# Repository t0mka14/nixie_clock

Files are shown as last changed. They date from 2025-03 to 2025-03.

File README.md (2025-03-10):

Another 6 digit nixie clock project. Uses Z570M digitrons, RpiPico and HV5530

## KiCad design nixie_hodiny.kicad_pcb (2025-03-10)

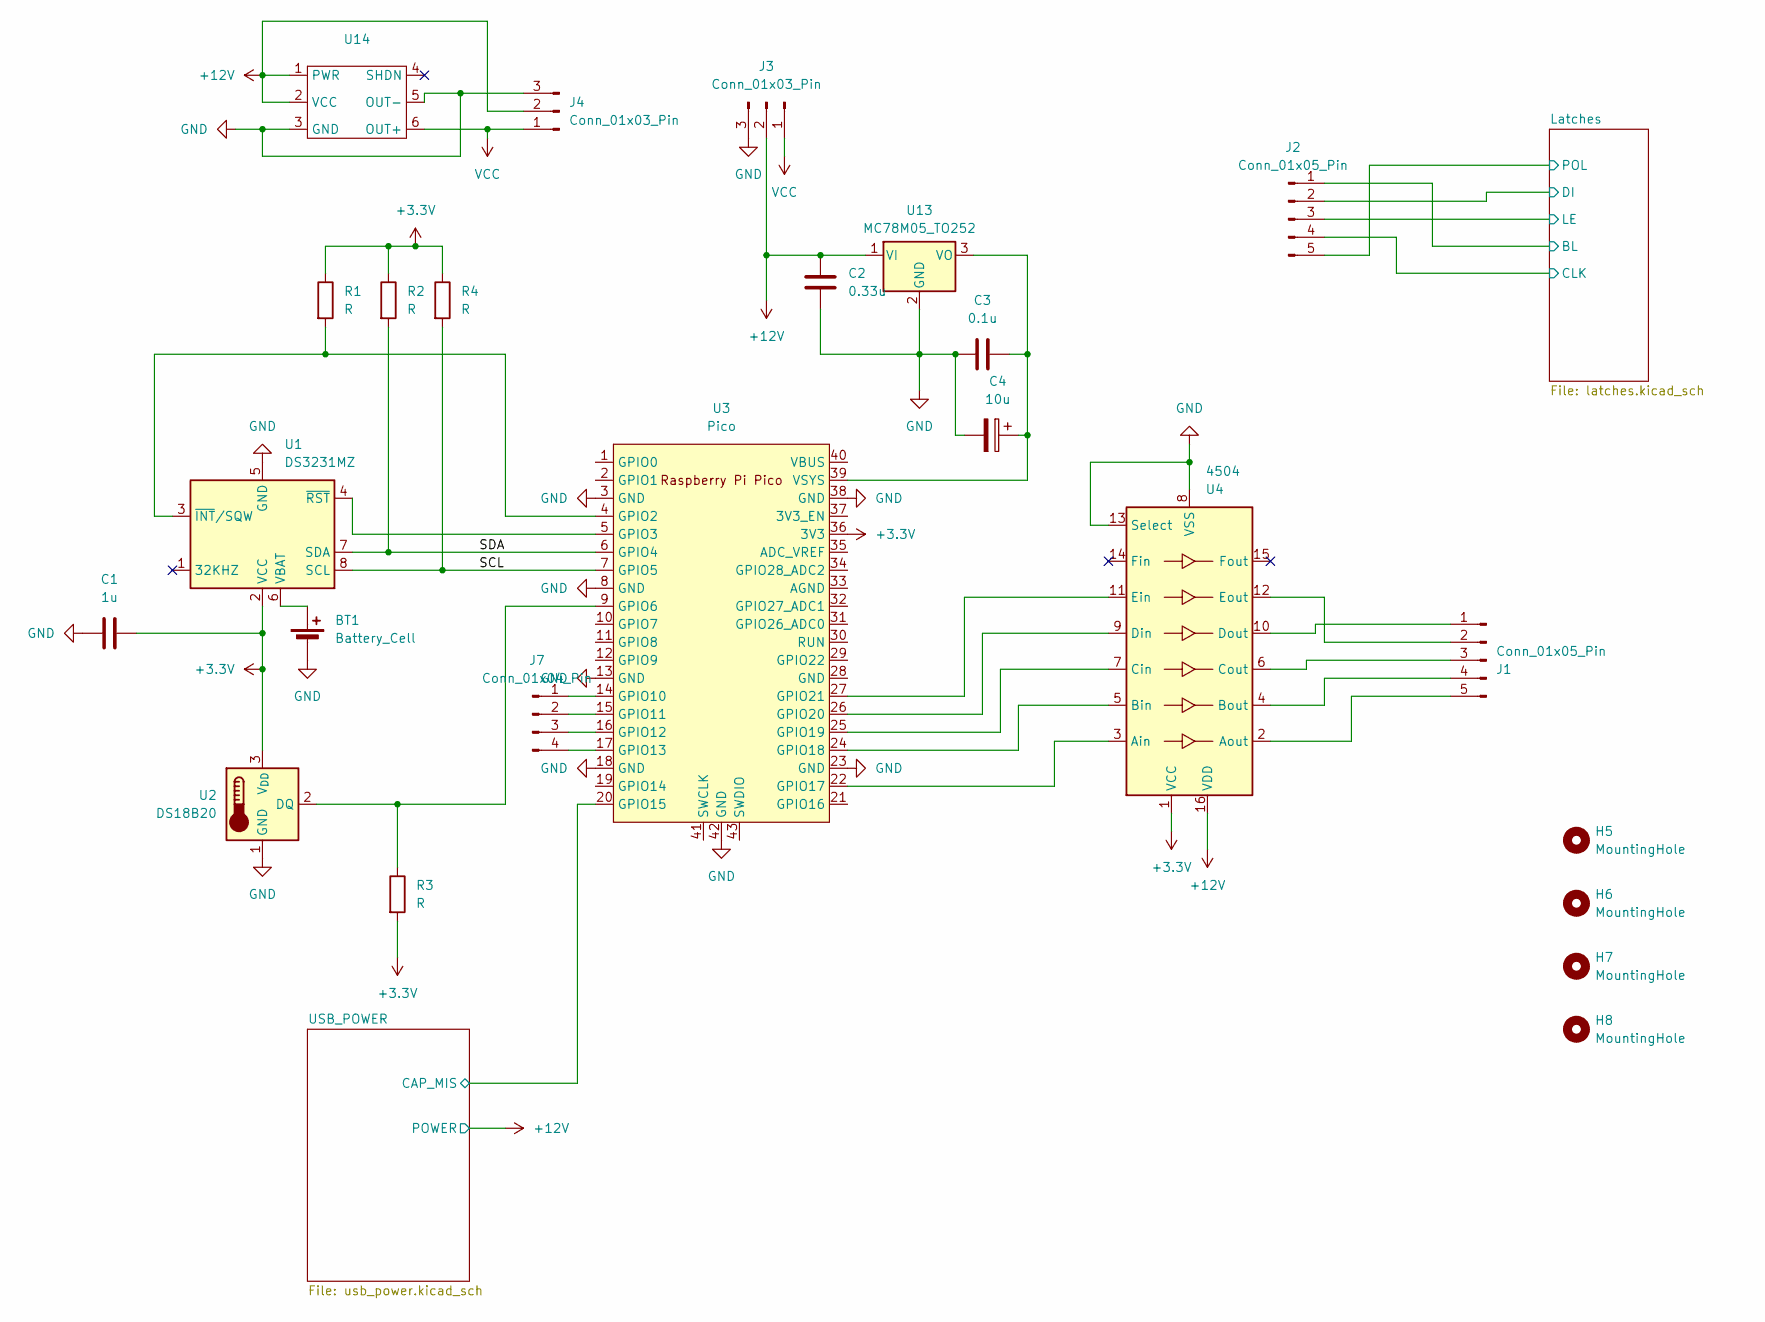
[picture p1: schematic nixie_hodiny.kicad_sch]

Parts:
BT1: Battery_Cell; Battery_Panasonic_CR2032-HFN_Horizontal_CircularHoles
C1: 1u; C_0805_2012Metric
C2: 0.33u; C_0805_2012Metric
C3: 0.1u; C_0805_2012Metric
C4: 10u; CP_Radial_D5.0mm_P2.00mm
H5, H6, H7, H8: MountingHole; MountingHole_3.2mm_M3
J1, J2: Conn_01x05_Pin; PinHeader_1x05_P2.54mm_Vertical
J3, J4: Conn_01x03_Pin; PinHeader_1x03_P2.54mm_Vertical
J7: Conn_01x04_Pin; PinHeader_1x04_P2.54mm_Vertical
R1, R2, R3, R4: R; R_0805_2012Metric
U1: DS3231MZ; SOIC-8_3.9x4.9mm_P1.27mm
U2: DS18B20; TO-92_Inline
U3: Pico; RPi_Pico_SMD_TH
U4: 4504; Texas_PDSO_G16
U13: MC78M05_TO252; TO-252-2
U14: nixie_supply

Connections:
+3.3V: C1.2, R1.1, R2.1, R3.2, R4.1, U1.2 (VCC), U2.3 (V_{DD}), U3.36 (3V3), U4.1 (VCC)
+12V: C2.1, J3.2, J4.2, U4.16 (VDD), U13.1 (VI), U14.1 (PWR), U14.2 (VCC); also elsewhere on the board
/Latches/BL: J2.1; also elsewhere on the board
/Latches/CLK: J2.4; also elsewhere on the board
/Latches/DI: J2.2; also elsewhere on the board
/Latches/LE: J2.3; also elsewhere on the board
/Latches/POL: J2.5; also elsewhere on the board
/SCL: R4.2, U1.8 (SCL), U3.7 (GPIO5)
/SDA: R2.2, U1.7 (SDA), U3.6 (GPIO4)
/USB_POWER/CAP_MIS: U3.20 (GPIO15); also elsewhere on the board
GND: BT1.2 (-), C1.1, C2.2, C3.1, C4.2, J3.3, J4.3, U1.5 (GND), U2.1 (GND), U3.3 (GND), U3.8 (GND), U3.13 (GND), U3.18 (GND), U3.23 (GND), U3.38 (GND), U3.42 (GND), U4.8 (VSS), U4.13 (Select), U13.2 (GND), U14.3 (GND), U14.5 (OUT-); also elsewhere on the board
unnamed: BT1.1 (+), U1.6 (VBAT)
unnamed: J1.1, U4.10 (Dout)
unnamed: J1.2, U4.12 (Eout)
unnamed: J1.3, U4.6 (Cout)
unnamed: J1.4, U4.4 (Bout)
unnamed: J1.5, U4.2 (Aout)
unnamed: J7.1, U3.14 (GPIO10)
unnamed: J7.2, U3.15 (GPIO11)
unnamed: J7.3, U3.16 (GPIO12)
unnamed: J7.4, U3.17 (GPIO13)
unnamed: R1.2, U1.3 (~INT/SQW), U3.4 (GPIO2)
unnamed: U1.4 (~RST), U3.5 (GPIO3)
unnamed: R3.1, U2.2 (DQ), U3.9 (GPIO6)
unnamed: U3.22 (GPIO17), U4.3 (Ain)
unnamed: U3.24 (GPIO18), U4.5 (Bin)
unnamed: U3.25 (GPIO19), U4.7 (Cin)
unnamed: U3.26 (GPIO20), U4.9 (Din)
unnamed: U3.27 (GPIO21), U4.11 (Ein)
unnamed: C3.2, C4.1, U3.39 (VSYS), U13.3 (VO)
VCC: J3.1, J4.1, U14.6 (OUT+); also elsewhere on the board

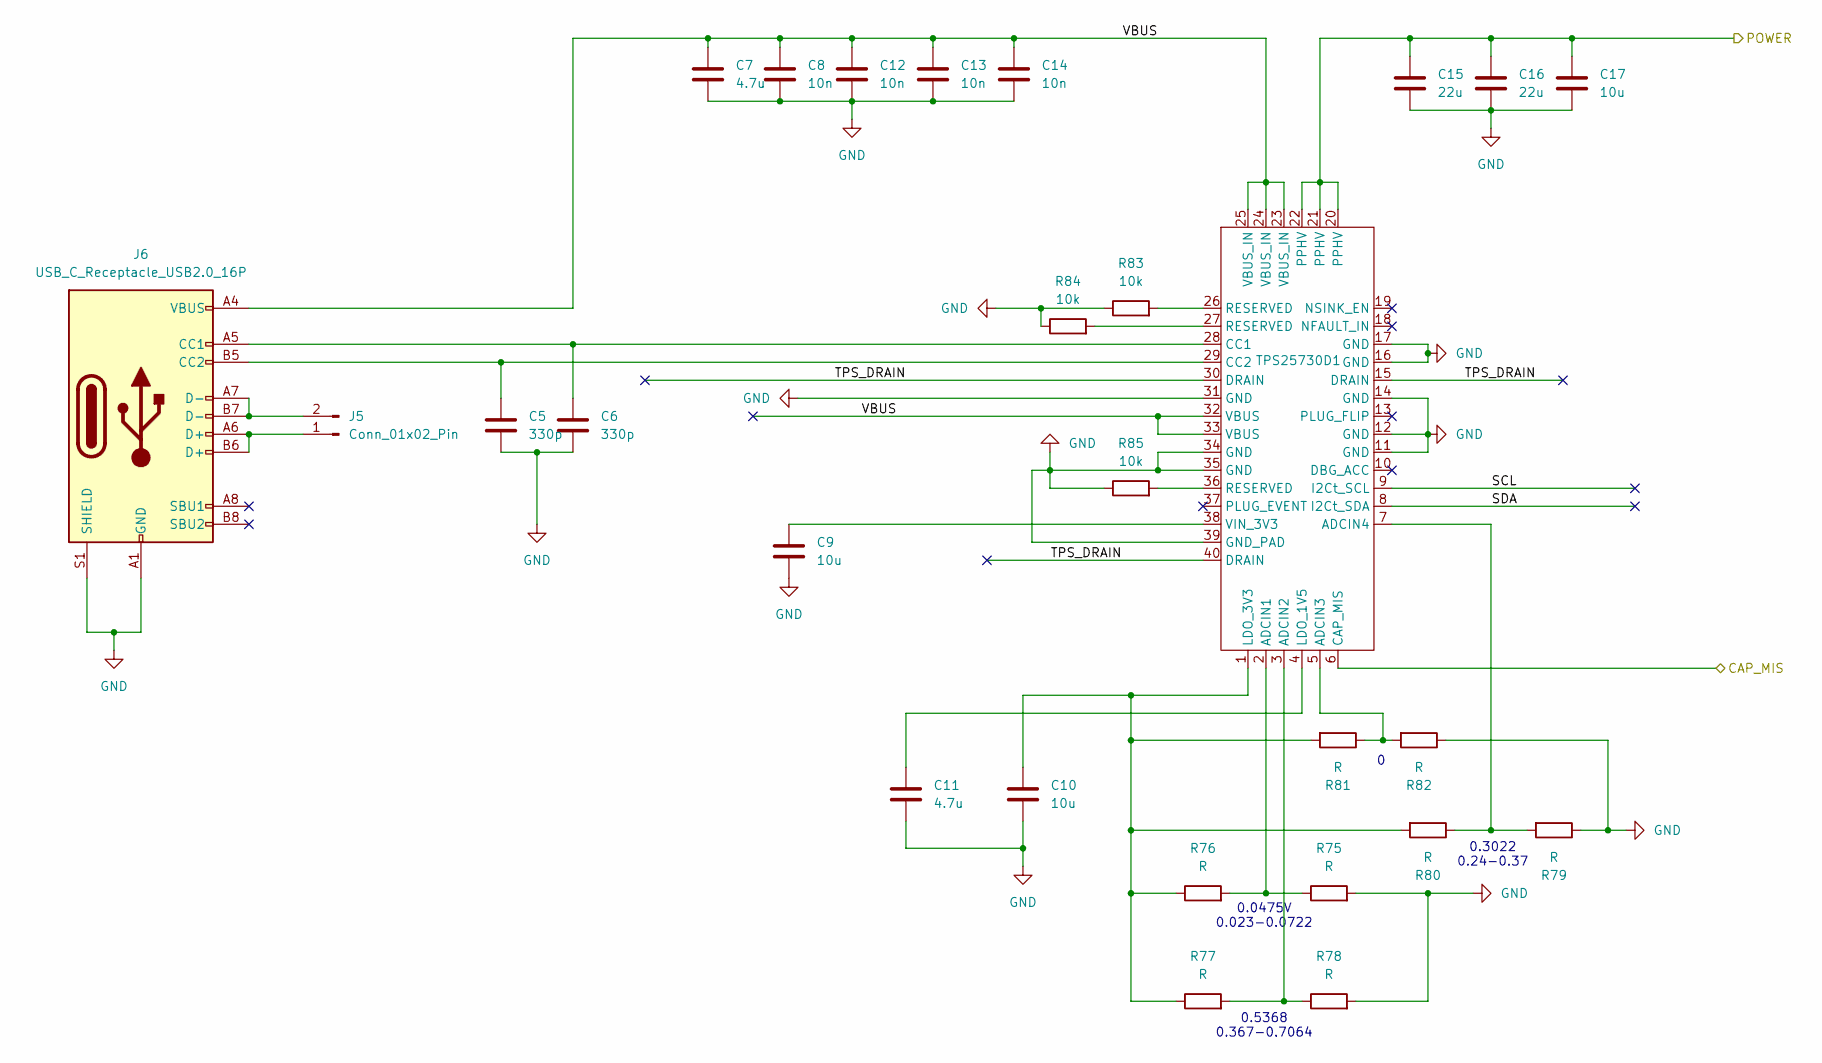
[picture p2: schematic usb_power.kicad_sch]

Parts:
C5, C6: 330p; C_0805_2012Metric
C7, C11: 4.7u; C_0805_2012Metric
C8, C12, C13, C14: 10n; C_0805_2012Metric
C9, C10, C17: 10u; C_0805_2012Metric
C15, C16: 22u; C_0805_2012Metric
J5: Conn_01x02_Pin; PinHeader_1x02_P2.54mm_Vertical
J6: USB_C_Receptacle_USB2.0_16P; Conn_USB_C_Socket_Molex_2171790001
R75, R76, R77, R78, R79, R80, R81, R82: R; R_0805_2012Metric
R83, R84, R85: 10k; R_0805_2012Metric
TPS25730D1: IC_TPS25730D

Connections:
+12V: C15.1, C16.1, C17.1, TPS25730D1.20 (PPHV), TPS25730D1.21 (PPHV), TPS25730D1.22 (PPHV); also elsewhere on the board
/USB_POWER/CAP_MIS: TPS25730D1.6 (CAP_MIS); also elsewhere on the board
/USB_POWER/SCL: TPS25730D1.9 (I2Ct_SCL)
/USB_POWER/SDA: TPS25730D1.8 (I2Ct_SDA)
/USB_POWER/TPS_DRAIN: TPS25730D1.15 (DRAIN), TPS25730D1.30 (DRAIN), TPS25730D1.40 (DRAIN)
/USB_POWER/VBUS: C7.1, C8.1, C12.1, C13.1, C14.1, J6.A4 (VBUS), J6.A9 (VBUS), J6.B4 (VBUS), J6.B9 (VBUS), TPS25730D1.23 (VBUS_IN), TPS25730D1.24 (VBUS_IN), TPS25730D1.25 (VBUS_IN), TPS25730D1.32 (VBUS), TPS25730D1.33 (VBUS)
GND: C5.2, C6.2, C7.2, C8.2, C9.1, C10.2, C11.2, C12.2, C13.2, C14.2, C15.2, C16.2, C17.2, J6.A1 (GND), J6.A12 (GND), J6.B1 (GND), J6.B12 (GND), J6.S1 (SHIELD), R75.2, R78.2, R79.1, R82.1, R83.1, R84.1, R85.1, TPS25730D1.11 (GND), TPS25730D1.12 (GND), TPS25730D1.14 (GND), TPS25730D1.16 (GND), TPS25730D1.17 (GND), TPS25730D1.31 (GND), TPS25730D1.34 (GND), TPS25730D1.35 (GND), TPS25730D1.39 (GND_PAD); also elsewhere on the board
unnamed: J5.1, J6.A6 (D+), J6.B6 (D+)
unnamed: J5.2, J6.A7 (D-), J6.B7 (D-)
unnamed: C6.1, J6.A5 (CC1), TPS25730D1.28 (CC1)
unnamed: C5.1, J6.B5 (CC2), TPS25730D1.29 (CC2)
unnamed: R83.2, TPS25730D1.26 (RESERVED)
unnamed: R84.2, TPS25730D1.27 (RESERVED)
unnamed: R85.2, TPS25730D1.36 (RESERVED)
unnamed: R75.1, R76.2, TPS25730D1.2 (ADCIN1)
unnamed: R77.2, R78.1, TPS25730D1.3 (ADCIN2)
unnamed: R81.1, R82.2, TPS25730D1.5 (ADCIN3)
unnamed: R79.2, R80.1, TPS25730D1.7 (ADCIN4)
unnamed: C11.1, TPS25730D1.4 (LDO_1V5)
unnamed: C10.1, R76.1, R77.1, R80.2, R81.2, TPS25730D1.1 (LDO_3V3)
unnamed: C9.2, TPS25730D1.38 (VIN_3V3)

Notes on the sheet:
0.5368 0.367-0.7064
0.3022 0.24-0.37
0.0475V 0.023-0.0722

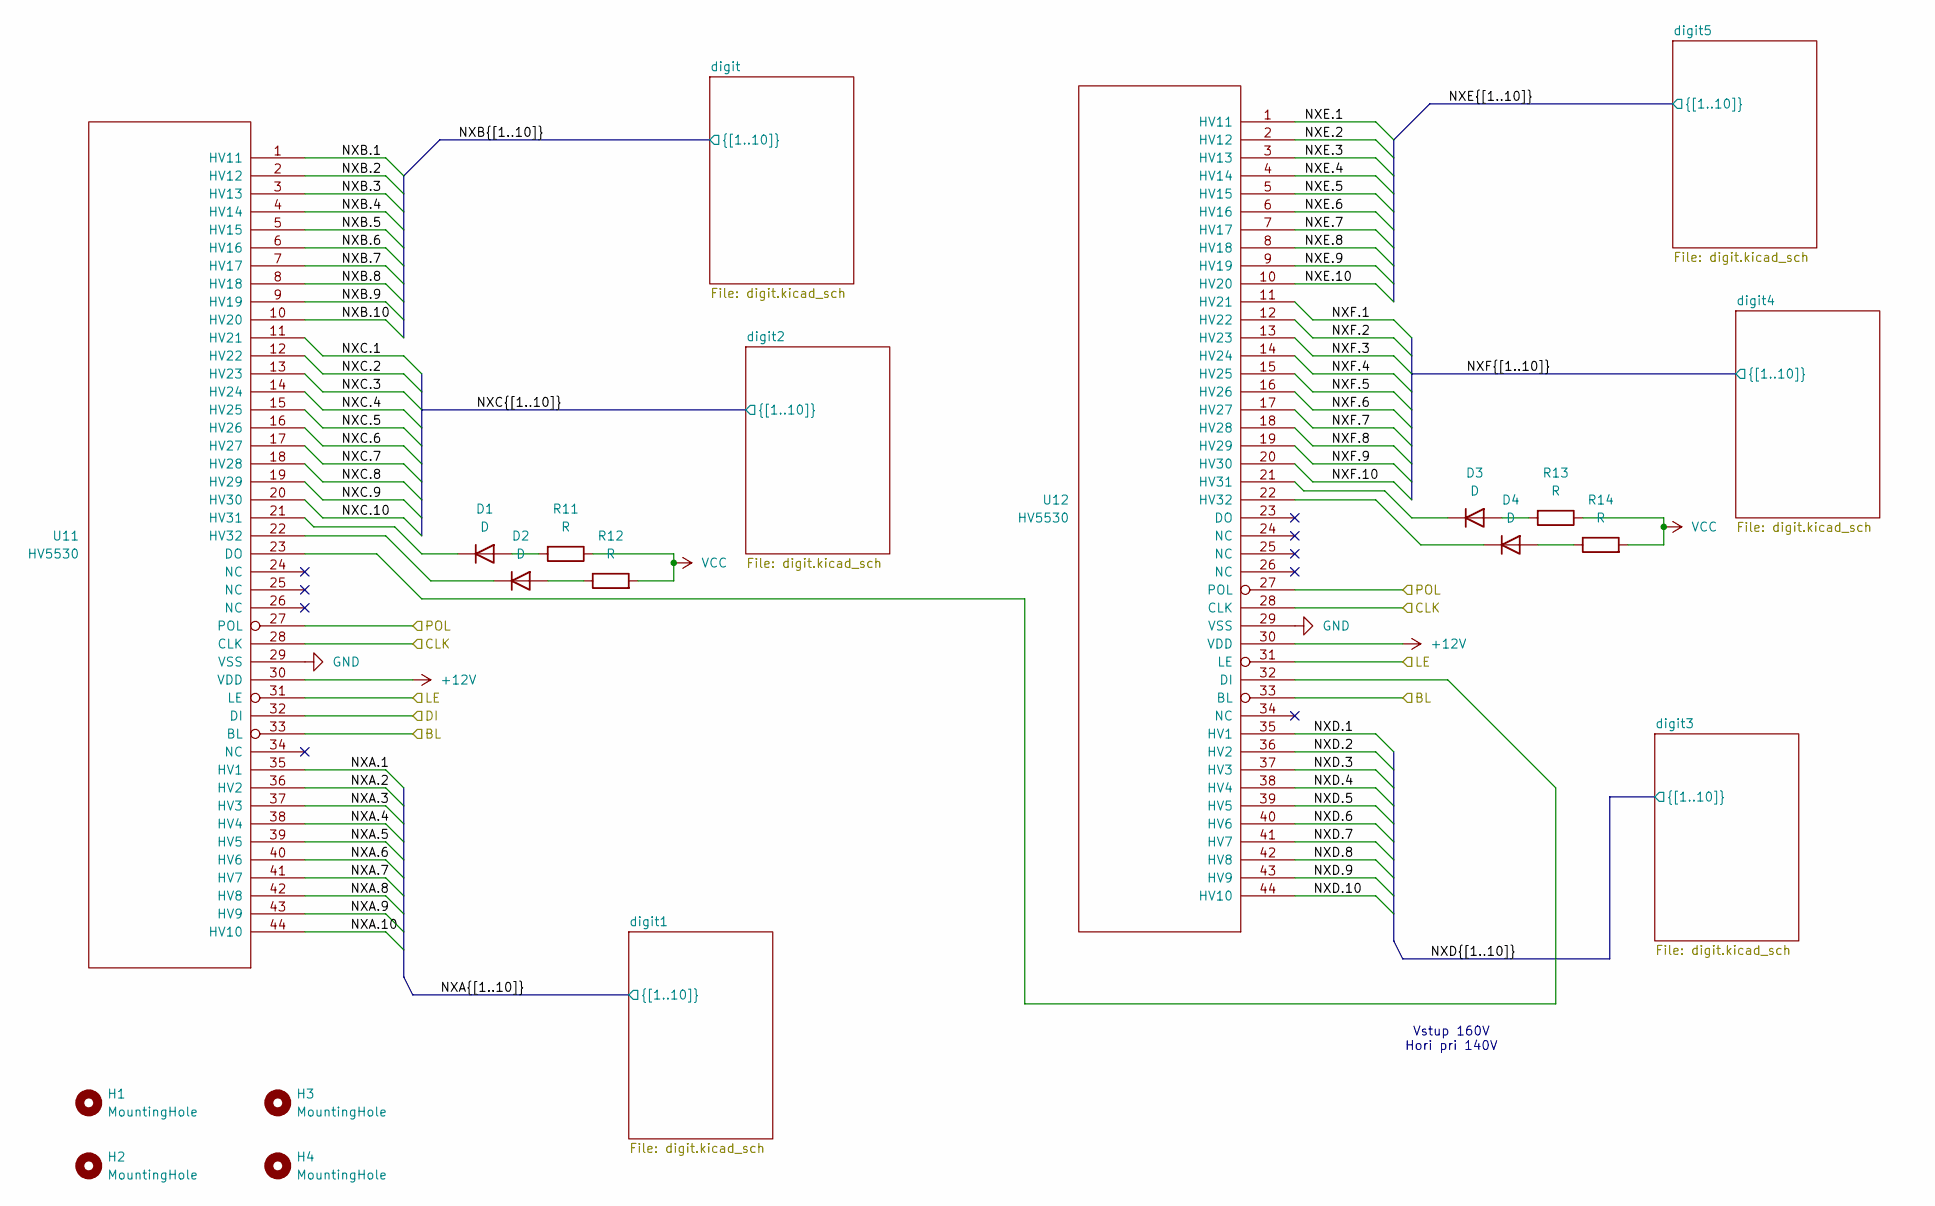
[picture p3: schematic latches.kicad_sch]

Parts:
D1, D2, D3, D4: D; CP_Radial_D8.0mm_P5.00mm
H1, H2, H3, H4: MountingHole; MountingHole_3.2mm_M3
R11, R12, R13, R14: R; R_1206_3216Metric
U11, U12: HV5530; PQFP-44_HV5530

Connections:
+12V: U11.30 (VDD), U12.30 (VDD); also elsewhere on the board
/Latches/BL: U11.33 (BL), U12.33 (BL); also elsewhere on the board
/Latches/CLK: U11.28 (CLK), U12.28 (CLK); also elsewhere on the board
/Latches/DI: U11.32 (DI); also elsewhere on the board
/Latches/LE: U11.31 (LE), U12.31 (LE); also elsewhere on the board
/Latches/NXA.1: U11.35 (HV1); also elsewhere on the board
/Latches/NXA.2: U11.36 (HV2); also elsewhere on the board
/Latches/NXA.3: U11.37 (HV3); also elsewhere on the board
/Latches/NXA.4: U11.38 (HV4); also elsewhere on the board
/Latches/NXA.5: U11.39 (HV5); also elsewhere on the board
/Latches/NXA.6: U11.40 (HV6); also elsewhere on the board
/Latches/NXA.7: U11.41 (HV7); also elsewhere on the board
/Latches/NXA.8: U11.42 (HV8); also elsewhere on the board
/Latches/NXA.9: U11.43 (HV9); also elsewhere on the board
/Latches/NXA.10: U11.44 (HV10); also elsewhere on the board
/Latches/NXB.1: U11.1 (HV11); also elsewhere on the board
/Latches/NXB.2: U11.2 (HV12); also elsewhere on the board
/Latches/NXB.3: U11.3 (HV13); also elsewhere on the board
/Latches/NXB.4: U11.4 (HV14); also elsewhere on the board
/Latches/NXB.5: U11.5 (HV15); also elsewhere on the board
/Latches/NXB.6: U11.6 (HV16); also elsewhere on the board
/Latches/NXB.7: U11.7 (HV17); also elsewhere on the board
/Latches/NXB.8: U11.8 (HV18); also elsewhere on the board
/Latches/NXB.9: U11.9 (HV19); also elsewhere on the board
/Latches/NXB.10: U11.10 (HV20); also elsewhere on the board
/Latches/NXC.1: U11.11 (HV21); also elsewhere on the board
/Latches/NXC.2: U11.12 (HV22); also elsewhere on the board
/Latches/NXC.3: U11.13 (HV23); also elsewhere on the board
/Latches/NXC.4: U11.14 (HV24); also elsewhere on the board
/Latches/NXC.5: U11.15 (HV25); also elsewhere on the board
/Latches/NXC.6: U11.16 (HV26); also elsewhere on the board
/Latches/NXC.7: U11.17 (HV27); also elsewhere on the board
/Latches/NXC.8: U11.18 (HV28); also elsewhere on the board
/Latches/NXC.9: U11.19 (HV29); also elsewhere on the board
/Latches/NXC.10: U11.20 (HV30); also elsewhere on the board
/Latches/NXD.1: U12.35 (HV1); also elsewhere on the board
/Latches/NXD.2: U12.36 (HV2); also elsewhere on the board
/Latches/NXD.3: U12.37 (HV3); also elsewhere on the board
/Latches/NXD.4: U12.38 (HV4); also elsewhere on the board
/Latches/NXD.5: U12.39 (HV5); also elsewhere on the board
/Latches/NXD.6: U12.40 (HV6); also elsewhere on the board
/Latches/NXD.7: U12.41 (HV7); also elsewhere on the board
/Latches/NXD.8: U12.42 (HV8); also elsewhere on the board
/Latches/NXD.9: U12.43 (HV9); also elsewhere on the board
/Latches/NXD.10: U12.44 (HV10); also elsewhere on the board
/Latches/NXE.1: U12.1 (HV11); also elsewhere on the board
/Latches/NXE.2: U12.2 (HV12); also elsewhere on the board
/Latches/NXE.3: U12.3 (HV13); also elsewhere on the board
/Latches/NXE.4: U12.4 (HV14); also elsewhere on the board
/Latches/NXE.5: U12.5 (HV15); also elsewhere on the board
/Latches/NXE.6: U12.6 (HV16); also elsewhere on the board
/Latches/NXE.7: U12.7 (HV17); also elsewhere on the board
/Latches/NXE.8: U12.8 (HV18); also elsewhere on the board
/Latches/NXE.9: U12.9 (HV19); also elsewhere on the board
/Latches/NXE.10: U12.10 (HV20); also elsewhere on the board
/Latches/NXF.1: U12.11 (HV21); also elsewhere on the board
/Latches/NXF.2: U12.12 (HV22); also elsewhere on the board
/Latches/NXF.3: U12.13 (HV23); also elsewhere on the board
/Latches/NXF.4: U12.14 (HV24); also elsewhere on the board
/Latches/NXF.5: U12.15 (HV25); also elsewhere on the board
/Latches/NXF.6: U12.16 (HV26); also elsewhere on the board
/Latches/NXF.7: U12.17 (HV27); also elsewhere on the board
/Latches/NXF.8: U12.18 (HV28); also elsewhere on the board
/Latches/NXF.9: U12.19 (HV29); also elsewhere on the board
/Latches/NXF.10: U12.20 (HV30); also elsewhere on the board
/Latches/POL: U11.27 (POL), U12.27 (POL); also elsewhere on the board
GND: U11.29 (VSS), U12.29 (VSS); also elsewhere on the board
unnamed: D1.2 (A), R11.2
unnamed: D1.1 (K), U11.21 (HV31)
unnamed: D2.2 (A), R12.1
unnamed: D2.1 (K), U11.22 (HV32)
unnamed: D3.2 (A), R13.2
unnamed: D3.1 (K), U12.21 (HV31)
unnamed: D4.2 (A), R14.1
unnamed: D4.1 (K), U12.22 (HV32)
unnamed: U11.23 (DO), U12.32 (DI)
VCC: R11.1, R12.2, R13.1, R14.2; also elsewhere on the board

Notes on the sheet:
Vstup 160V Hori pri 140V

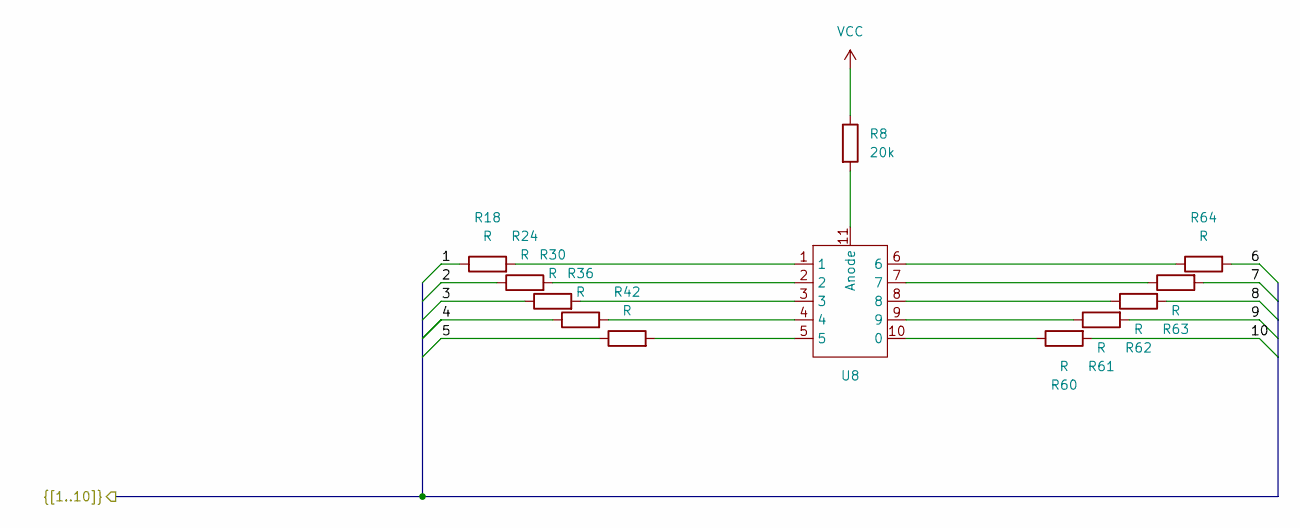
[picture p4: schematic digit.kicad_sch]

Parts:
R8: 20k; R_1206_3216Metric
R18, R24, R30, R36, R42, R60, R61, R62, R63, R64: R; R_0805_2012Metric
U8: Z570M_patice

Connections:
/Latches/NXD.1: R18.1; also elsewhere on the board
/Latches/NXD.2: R24.1; also elsewhere on the board
/Latches/NXD.3: R30.1; also elsewhere on the board
/Latches/NXD.4: R36.1; also elsewhere on the board
/Latches/NXD.5: R42.1; also elsewhere on the board
/Latches/NXD.6: R64.2; also elsewhere on the board
/Latches/NXD.7: R63.2; also elsewhere on the board
/Latches/NXD.8: R62.2; also elsewhere on the board
/Latches/NXD.9: R61.2; also elsewhere on the board
/Latches/NXD.10: R60.2; also elsewhere on the board
unnamed: R18.2, U8.1
unnamed: R24.2, U8.2
unnamed: R30.2, U8.3
unnamed: R36.2, U8.4
unnamed: R42.2, U8.5
unnamed: R61.1, U8.9
unnamed: R62.1, U8.8
unnamed: R63.1, U8.7
unnamed: R64.1, U8.6
unnamed: R60.1, U8.10 (0)
unnamed: R8.2, U8.11 (Anode)
VCC: R8.1; also elsewhere on the board

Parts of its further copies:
R5, R6, R7, R9, R10: 20k; R_1206_3216Metric
R15, R16, R17, R19, R20, R21, R22, R23, R25, R26, R27, R28, R29, R31, R32, R33, R34, R35, R37, R38, R39, R40, R41, R43, R44, R45, R46, R47, R48, R49, R50, R51, R52, R53, R54, R55, R56, R57, R58, R59, R65, R66, R67, R68, R69, R70, R71, R72, R73, R74: R; R_0805_2012Metric
U5, U6, U7, U9, U10: Z570M_patice

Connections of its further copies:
/Latches/NXA.1: R16.1; also elsewhere on the board
/Latches/NXA.2: R22.1; also elsewhere on the board
/Latches/NXA.3: R28.1; also elsewhere on the board
/Latches/NXA.4: R34.1; also elsewhere on the board
/Latches/NXA.5: R40.1; also elsewhere on the board
/Latches/NXA.6: R54.2; also elsewhere on the board
/Latches/NXA.7: R53.2; also elsewhere on the board
/Latches/NXA.8: R52.2; also elsewhere on the board
/Latches/NXA.9: R51.2; also elsewhere on the board
/Latches/NXA.10: R50.2; also elsewhere on the board
/Latches/NXB.1: R15.1; also elsewhere on the board
/Latches/NXB.2: R21.1; also elsewhere on the board
/Latches/NXB.3: R27.1; also elsewhere on the board
/Latches/NXB.4: R33.1; also elsewhere on the board
/Latches/NXB.5: R39.1; also elsewhere on the board
/Latches/NXB.6: R49.2; also elsewhere on the board
/Latches/NXB.7: R48.2; also elsewhere on the board
/Latches/NXB.8: R47.2; also elsewhere on the board
/Latches/NXB.9: R46.2; also elsewhere on the board
/Latches/NXB.10: R45.2; also elsewhere on the board
/Latches/NXC.1: R17.1; also elsewhere on the board
/Latches/NXC.2: R23.1; also elsewhere on the board
/Latches/NXC.3: R29.1; also elsewhere on the board
/Latches/NXC.4: R35.1; also elsewhere on the board
/Latches/NXC.5: R41.1; also elsewhere on the board
/Latches/NXC.6: R59.2; also elsewhere on the board
/Latches/NXC.7: R58.2; also elsewhere on the board
/Latches/NXC.8: R57.2; also elsewhere on the board
/Latches/NXC.9: R56.2; also elsewhere on the board
/Latches/NXC.10: R55.2; also elsewhere on the board
/Latches/NXE.1: R20.1; also elsewhere on the board
/Latches/NXE.2: R26.1; also elsewhere on the board
/Latches/NXE.3: R32.1; also elsewhere on the board
/Latches/NXE.4: R38.1; also elsewhere on the board
/Latches/NXE.5: R44.1; also elsewhere on the board
/Latches/NXE.6: R74.2; also elsewhere on the board
/Latches/NXE.7: R73.2; also elsewhere on the board
/Latches/NXE.8: R72.2; also elsewhere on the board
/Latches/NXE.9: R71.2; also elsewhere on the board
/Latches/NXE.10: R70.2; also elsewhere on the board
/Latches/NXF.1: R19.1; also elsewhere on the board
/Latches/NXF.2: R25.1; also elsewhere on the board
/Latches/NXF.3: R31.1; also elsewhere on the board
/Latches/NXF.4: R37.1; also elsewhere on the board
/Latches/NXF.5: R43.1; also elsewhere on the board
/Latches/NXF.6: R69.2; also elsewhere on the board
/Latches/NXF.7: R68.2; also elsewhere on the board
/Latches/NXF.8: R67.2; also elsewhere on the board
/Latches/NXF.9: R66.2; also elsewhere on the board
/Latches/NXF.10: R65.2; also elsewhere on the board
unnamed: R15.2, U5.1
unnamed: R16.2, U6.1
unnamed: R17.2, U7.1
unnamed: R19.2, U9.1
unnamed: R20.2, U10.1
unnamed: R21.2, U5.2
unnamed: R22.2, U6.2
unnamed: R23.2, U7.2
unnamed: R25.2, U9.2
unnamed: R26.2, U10.2
unnamed: R27.2, U5.3
unnamed: R28.2, U6.3
unnamed: R29.2, U7.3
unnamed: R31.2, U9.3
unnamed: R32.2, U10.3
unnamed: R33.2, U5.4
unnamed: R34.2, U6.4
unnamed: R35.2, U7.4
unnamed: R37.2, U9.4
unnamed: R38.2, U10.4
unnamed: R39.2, U5.5
unnamed: R40.2, U6.5
unnamed: R41.2, U7.5
unnamed: R43.2, U9.5
unnamed: R44.2, U10.5
unnamed: R46.1, U5.9
unnamed: R47.1, U5.8
unnamed: R48.1, U5.7
unnamed: R49.1, U5.6
unnamed: R51.1, U6.9
unnamed: R52.1, U6.8
unnamed: R53.1, U6.7
unnamed: R54.1, U6.6
unnamed: R56.1, U7.9
unnamed: R57.1, U7.8
unnamed: R58.1, U7.7
unnamed: R59.1, U7.6
unnamed: R66.1, U9.9
unnamed: R67.1, U9.8
unnamed: R68.1, U9.7
unnamed: R69.1, U9.6
unnamed: R71.1, U10.9
unnamed: R72.1, U10.8
unnamed: R73.1, U10.7
unnamed: R74.1, U10.6
unnamed: R45.1, U5.10 (0)
unnamed: R5.2, U5.11 (Anode)
unnamed: R50.1, U6.10 (0)
unnamed: R6.2, U6.11 (Anode)
unnamed: R55.1, U7.10 (0)
unnamed: R7.2, U7.11 (Anode)
unnamed: R65.1, U9.10 (0)
unnamed: R9.2, U9.11 (Anode)
unnamed: R70.1, U10.10 (0)
unnamed: R10.2, U10.11 (Anode)
VCC: R5.1, R6.1, R7.1, R9.1, R10.1; also elsewhere on the board

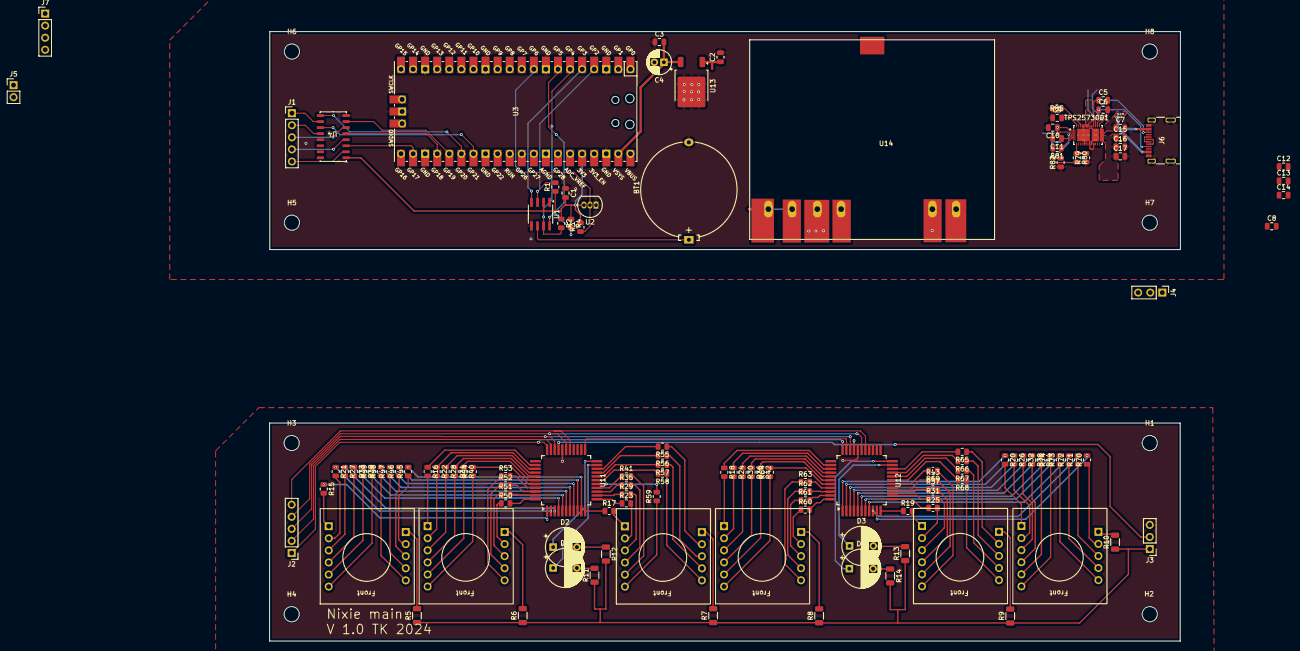
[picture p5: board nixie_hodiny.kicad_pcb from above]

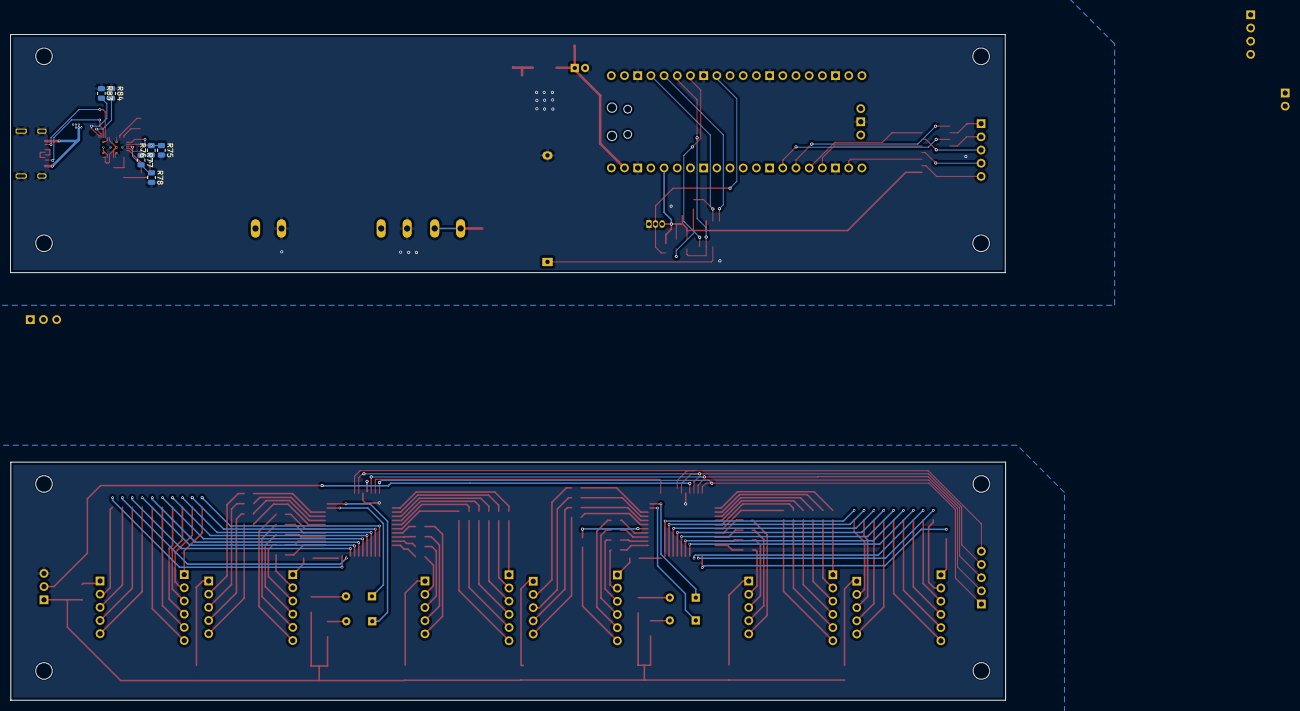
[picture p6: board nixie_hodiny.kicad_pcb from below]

Board: 2 copper layers, 191.6 x 128.2 mm, 137 parts (6 on the bottom side), 182 nets.
